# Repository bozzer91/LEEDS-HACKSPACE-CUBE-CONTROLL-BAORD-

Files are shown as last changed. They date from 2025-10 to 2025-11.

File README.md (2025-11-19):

# LEEDS HACKSPACE CUBE CONTROLL BOARD

# This READ me is a work in progress, please check back soon  :

This repository is for the new control board for the Leeds hackspace Cube art installation, this board will take input from a pc and output commands to the 16 Lines of addressable LEDS at 5v logic.  



wiring diagram visualisation ( not final revision) 



( the cube ) 

## Board info :

### Purpose : 
This control board is designed to take a Raspberry pi pico / pico-W and convert 16 data lines from 3v3 voltage to 5volt data and output this to the 16 LED strings of the Hackspace Cube. this board also includes extra ports for expansion and other functions for future upgrades. the board is about 10cm by 6cm and is deigned to be placed into an encloser with the users connectors of choice attached and soldered onto the PCB DATA outputs.   

### Reference text: 





The test points for the DATA and GPIO are as follows.
Data: to the left-hand side of the resistor above " D-1 example " the label. the left hand side is 5v

GPIO: test point to the right-hand side of the resistor below the labelling. with the left hand side being 3v3 volts

see below for the visual.



### Spare pin header :
The pin header by pins 16-28 are spare for future expansion of the cube the numbers listed on the PCB are the GPIO numbers of the pico. There are extra GND pins to the right of this pin header.



### Smothing caps :
There are 100nf smoothing caps on the main voltage rails for 5v and 3v3 these are set at locations around the board first set next to the pico and then one set pure bank of 4 logic shifters. ( see below images for examples )





### Main outputs : 
The controller board has two main Data output connectors in the form of two sets of pinheaders to connect to the users connector of choice this also mimicked the original breadboard design and allows for drop in replacement if required using the original ribbon cables. 

Connector 1 = Data 1-8 plus one GND pin
Connector 2 = Data 9-16 plus one GND pin




### Power : 
This controller board is powered by the Pico's usb input port. 

## History of this project: 

So some history of this project. back in 2022 ( give or take a covid lockdown ) it was found that the original micro controller board for the cube had broken. work was undertaken to revers engineer this board and make a replacement for 2022 Leeds lightweight. roll on to 2025 and we are still using the fear inducing Bread board that looks like something you find in a suite case in a mission impossible film that needs defusing ( see below image ) so when packing down the cube i decided to make a pcb to replace this and help move the Cube to a more user friendly plug and play design. 

BREAD BOARD 


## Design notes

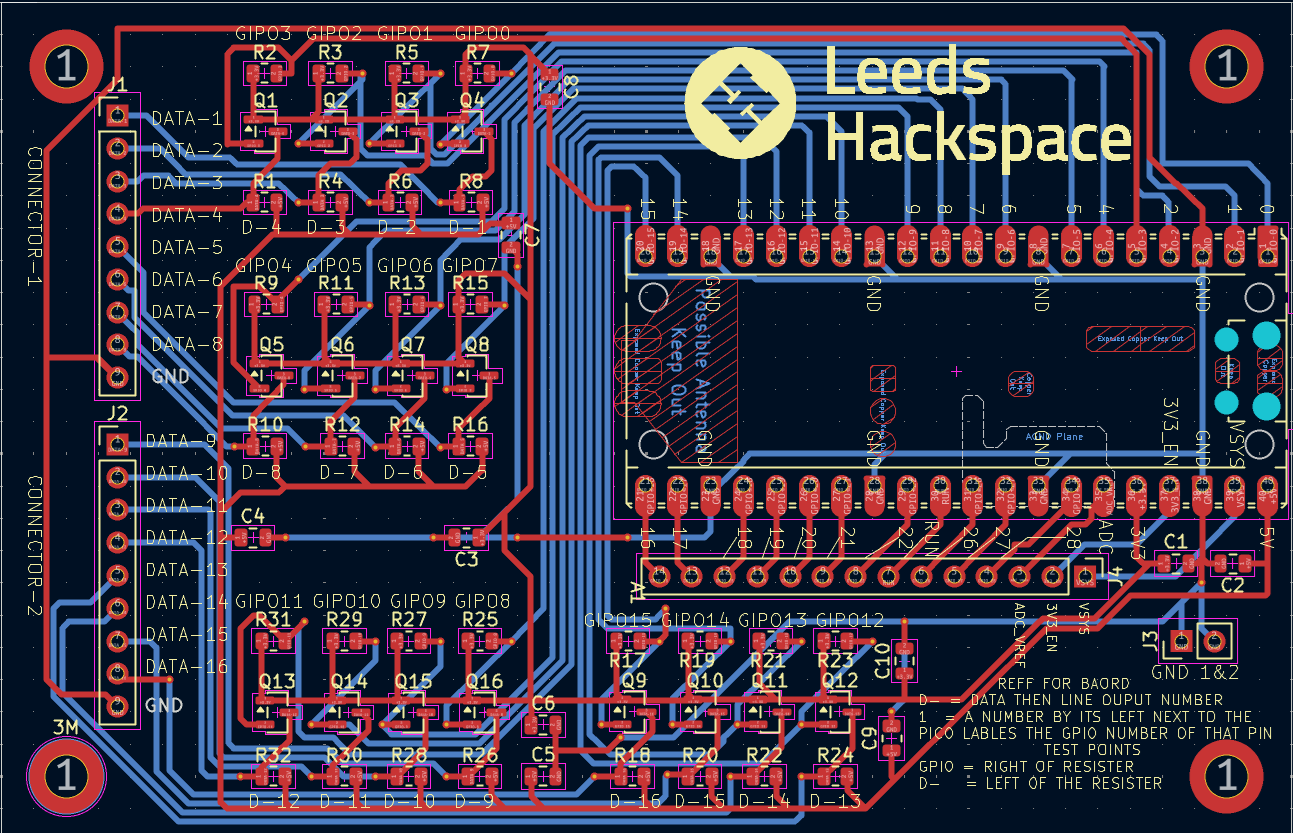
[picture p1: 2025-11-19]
Pcb layout ( spelling worng and no GND plain for easy viewing ).png

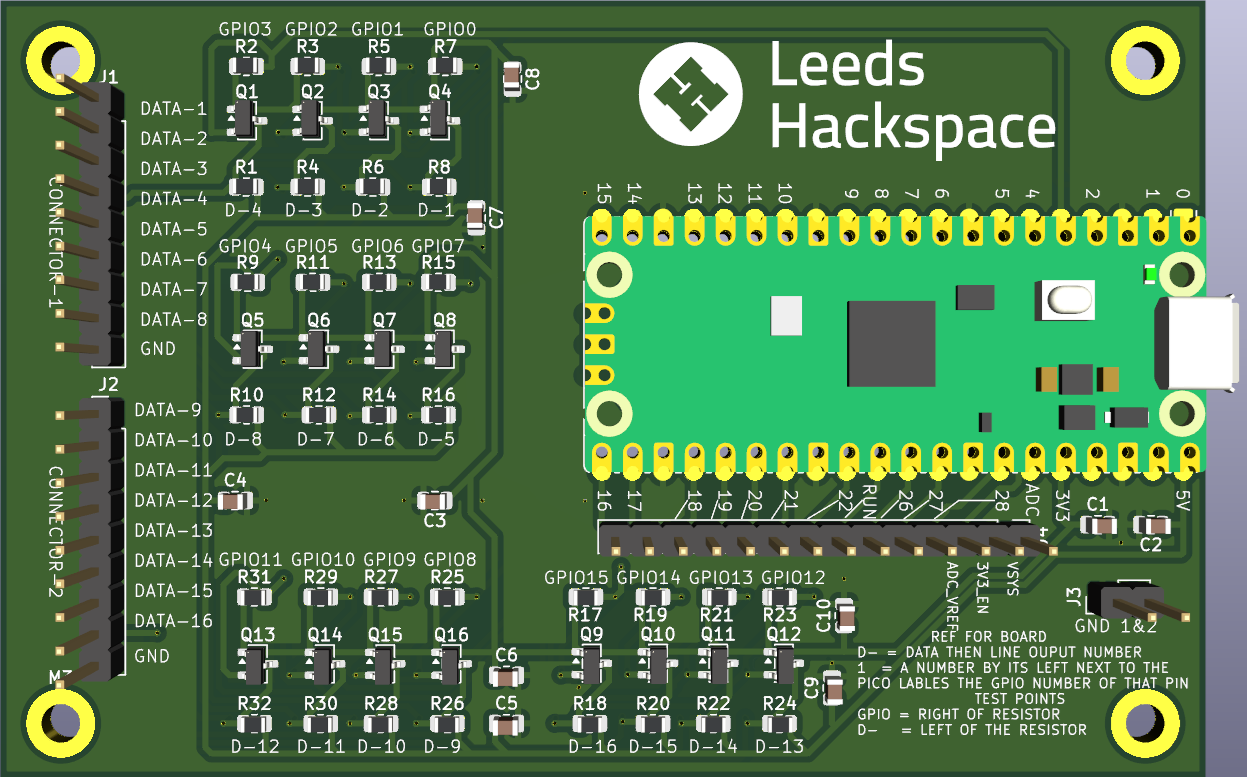
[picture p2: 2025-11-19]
PCB 3d render ( final complete version ).png

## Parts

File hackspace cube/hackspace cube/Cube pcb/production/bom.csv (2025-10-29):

Designator | Footprint | Quantity | Value | LCSC Part #
_3, _2, |  | 3
A1 | RaspberryPi_Pico_Common_Unspecified | 1 | RaspberryPi_Pico
C1, C10, C2, C3, C4, C5, C6, C7, C8, C9 | 0805 | 10 | 100nF
J1 | PinHeader_1x09_P2.54mm_Vertical | 1 | Conn_01x09 ( conector 1)
J2 | PinHeader_1x09_P2.54mm_Vertical | 1 | Conn_01x09 ( conector 2)
J3 | PinHeader_1x02_P2.54mm_Vertical | 1 | Conn_01x02 ( exstra ground conectors )
J4 | PinHeader_1x14_P2.54mm_Vertical | 1 | Conn_01x14 ( Spare Ports )
Q1, Q10, Q11, Q12, Q13, Q14, Q15, Q16, Q2, Q3, Q4, Q5, Q6, Q7, Q8, Q9 | SOT-23 | 16 | BSS138
R1, R10, R11, R12, R13, R14, R15, R16, R17, R18, R19, R2, R20, R21, R22, R23, R24, R25, R26, R27, R28, R29, R3, R30, R31, R32, R4, R5, R6, R7, R8, R9 | 0805 | 32 | 10k

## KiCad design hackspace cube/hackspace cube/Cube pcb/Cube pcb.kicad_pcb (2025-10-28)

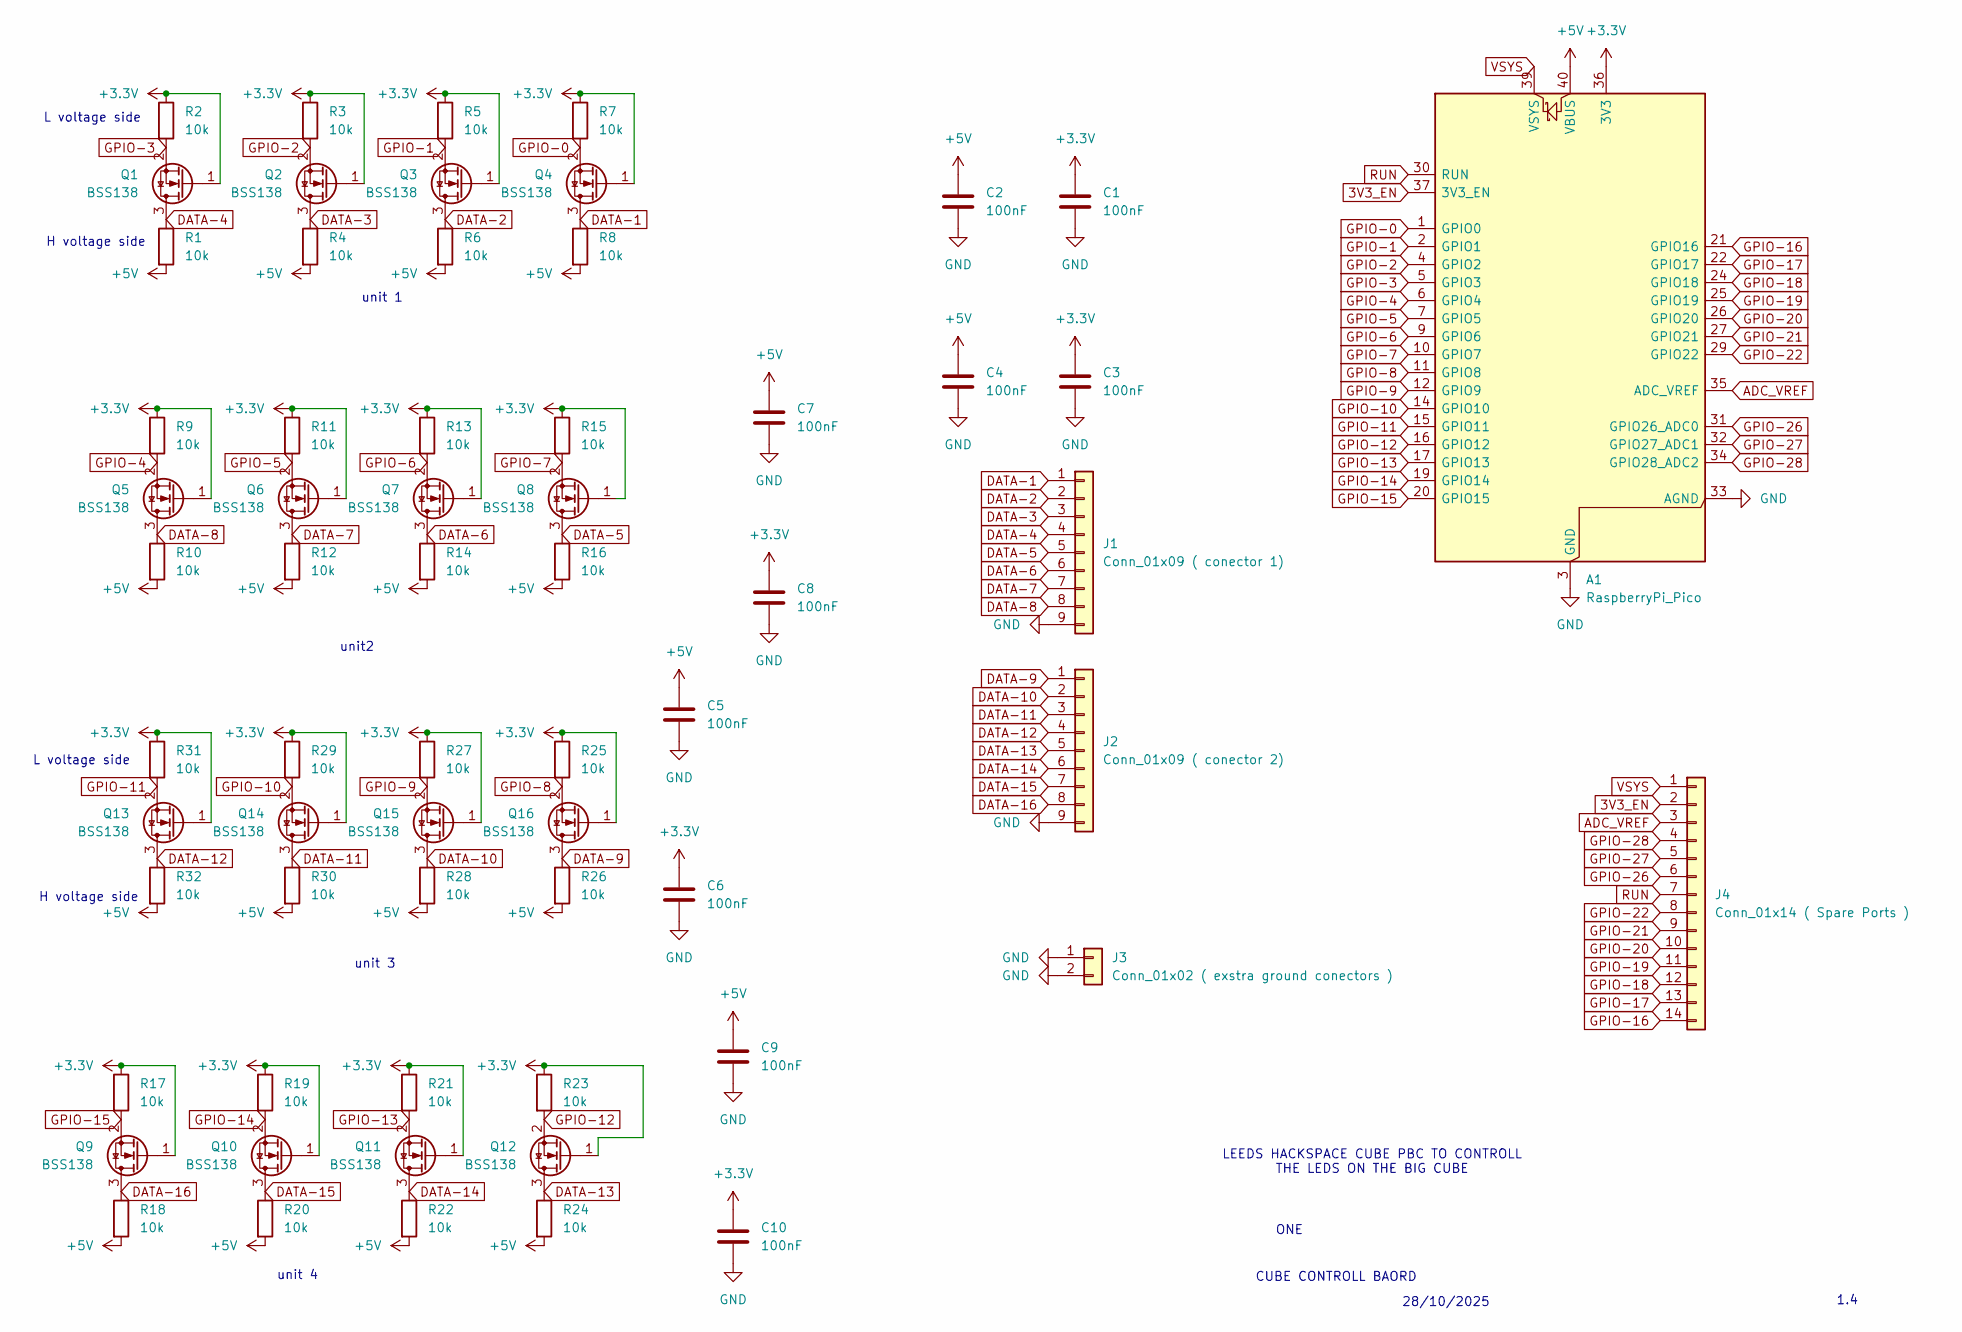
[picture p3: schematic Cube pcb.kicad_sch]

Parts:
A1: RaspberryPi_Pico; RaspberryPi_Pico_Common_Unspecified
C1, C2, C3, C4, C5, C6, C7, C8, C9, C10: 100nF; C_0805_2012Metric
J1: Conn_01x09 ( conector 1); PinHeader_1x09_P2.54mm_Vertical
J2: Conn_01x09 ( conector 2); PinHeader_1x09_P2.54mm_Vertical
J3: Conn_01x02 ( exstra ground conectors ); PinHeader_1x02_P2.54mm_Vertical
J4: Conn_01x14 ( Spare Ports ); PinHeader_1x14_P2.54mm_Vertical
Q1, Q2, Q3, Q4, Q5, Q6, Q7, Q8, Q9, Q10, Q11, Q12, Q13, Q14, Q15, Q16: BSS138; SOT-23
R1, R2, R3, R4, R5, R6, R7, R8, R9, R10, R11, R12, R13, R14, R15, R16, R17, R18, R19, R20, R21, R22, R23, R24, R25, R26, R27, R28, R29, R30, R31, R32: 10k; R_0805_2012Metric

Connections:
3V3_EN: A1.37 (3V3_EN), J4.2
+3.3V: A1.36 (3V3), C1.1, C3.1, C6.1, C8.1, C10.1, Q1.1 (G), Q2.1 (G), Q3.1 (G), Q4.1 (G), Q5.1 (G), Q6.1 (G), Q7.1 (G), Q8.1 (G), Q9.1 (G), Q10.1 (G), Q11.1 (G), Q12.1 (G), Q13.1 (G), Q14.1 (G), Q15.1 (G), Q16.1 (G), R2.1, R3.1, R5.1, R7.1, R9.1, R11.1, R13.1, R15.1, R17.1, R19.1, R21.1, R23.1, R25.1, R27.1, R29.1, R31.1
+5V: A1.40 (VBUS), C2.1, C4.1, C5.1, C7.1, C9.1, R1.2, R4.2, R6.2, R8.2, R10.2, R12.2, R14.2, R16.2, R18.2, R20.2, R22.2, R24.2, R26.2, R28.2, R30.2, R32.2
ADC_VREF: A1.35 (ADC_VREF), J4.3
DATA-1: J1.1, Q4.3 (D), R8.1
DATA-2: J1.2, Q3.3 (D), R6.1
DATA-3: J1.3, Q2.3 (D), R4.1
DATA-4: J1.4, Q1.3 (D), R1.1
DATA-5: J1.5, Q8.3 (D), R16.1
DATA-6: J1.6, Q7.3 (D), R14.1
DATA-7: J1.7, Q6.3 (D), R12.1
DATA-8: J1.8, Q5.3 (D), R10.1
DATA-9: J2.1, Q16.3 (D), R26.1
DATA-10: J2.2, Q15.3 (D), R28.1
DATA-11: J2.3, Q14.3 (D), R30.1
DATA-12: J2.4, Q13.3 (D), R32.1
DATA-13: J2.5, Q12.3 (D), R24.1
DATA-14: J2.6, Q11.3 (D), R22.1
DATA-15: J2.7, Q10.3 (D), R20.1
DATA-16: J2.8, Q9.3 (D), R18.1
GND: A1.3 (GND), A1.8 (GND), A1.13 (GND), A1.18 (GND), A1.23 (GND), A1.28 (GND), A1.33 (AGND), A1.38 (GND), C1.2, C2.2, C3.2, C4.2, C5.2, C6.2, C7.2, C8.2, C9.2, C10.2, J1.9, J2.9, J3.1, J3.2
GPIO-0: A1.1 (GPIO0), Q4.2 (S), R7.2
GPIO-1: A1.2 (GPIO1), Q3.2 (S), R5.2
GPIO-2: A1.4 (GPIO2), Q2.2 (S), R3.2
GPIO-3: A1.5 (GPIO3), Q1.2 (S), R2.2
GPIO-4: A1.6 (GPIO4), Q5.2 (S), R9.2
GPIO-5: A1.7 (GPIO5), Q6.2 (S), R11.2
GPIO-6: A1.9 (GPIO6), Q7.2 (S), R13.2
GPIO-7: A1.10 (GPIO7), Q8.2 (S), R15.2
GPIO-8: A1.11 (GPIO8), Q16.2 (S), R25.2
GPIO-9: A1.12 (GPIO9), Q15.2 (S), R27.2
GPIO-10: A1.14 (GPIO10), Q14.2 (S), R29.2
GPIO-11: A1.15 (GPIO11), Q13.2 (S), R31.2
GPIO-12: A1.16 (GPIO12), Q12.2 (S), R23.2
GPIO-13: A1.17 (GPIO13), Q11.2 (S), R21.2
GPIO-14: A1.19 (GPIO14), Q10.2 (S), R19.2
GPIO-15: A1.20 (GPIO15), Q9.2 (S), R17.2
GPIO-16: A1.21 (GPIO16), J4.14
GPIO-17: A1.22 (GPIO17), J4.13
GPIO-18: A1.24 (GPIO18), J4.12
GPIO-19: A1.25 (GPIO19), J4.11
GPIO-20: A1.26 (GPIO20), J4.10
GPIO-21: A1.27 (GPIO21), J4.9
GPIO-22: A1.29 (GPIO22), J4.8
GPIO-26: A1.31 (GPIO26_ADC0), J4.6
GPIO-27: A1.32 (GPIO27_ADC1), J4.5
GPIO-28: A1.34 (GPIO28_ADC2), J4.4
RUN: A1.30 (RUN), J4.7
VSYS: A1.39 (VSYS), J4.1

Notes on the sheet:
CUBE CONTROLL BAORD
unit 4
LEEDS HACKSPACE CUBE PBC TO CONTROLL THE LEDS ON THE BIG CUBE
unit 1
unit2
28/10/2025
unit 3
1.4
H voltage side
ONE
L voltage side

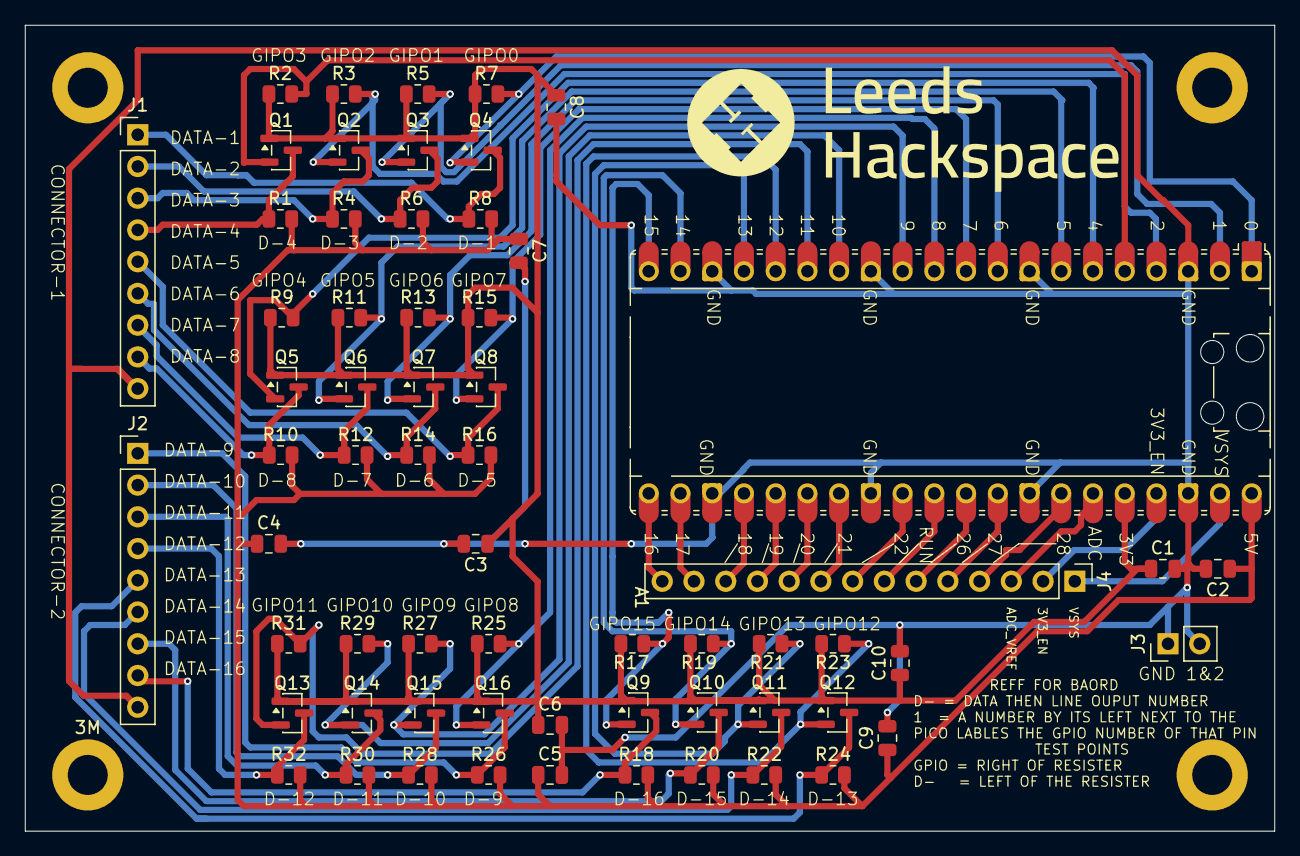
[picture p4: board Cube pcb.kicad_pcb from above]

Board: 2 copper layers, 100.0 x 64.5 mm, 64 parts (0 on the bottom side), 49 nets.

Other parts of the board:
3M: MountingHole_3.2mm_M3_ISO7380_Pad

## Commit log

2025-10-25 CUBE KI CAD FILES
2025-10-25 rev1.2 with pcb
    starting on pcb design
    [Cube pcb.kicad_pcb, Cube pcb.kicad_sch]
2025-10-26 updating pcb
    updating pcb most pins attached
    [Cube pcb.kicad_pcb]
2025-10-26 pcb first draft
    [Cube pcb.kicad_pcb, Cube pcb.kicad_sch]
2025-10-26 Update README.md
    UPDATING WITH INFO ON THE PCB
2025-10-26 update pcb
    i have added labels and basic info onto the pcb
    [Cube pcb.kicad_pcb]
2025-10-27 updated wiring D and PCB
    wiring D now has GND on the connector pins . PCB now has new shorter design to make it 10cm wide just need to add ground plain
    [Cube pcb.kicad_pcb, Cube pcb.kicad_sch]
2025-10-27 new pcb file
    new pcb file to add ground plain before sending off
    [Cube pcb - with ground plain.kicad_pcb]
2025-10-27 ground plain added
    ground plain added
    [Cube pcb - with ground plain.kicad_pcb]
2025-10-28 rev 1.4
    added new smooth caps and updated pcb
    [Cube pcb - with ground plain2.kicad_pcb, Cube pcb.kicad_pcb, Cube pcb.kicad_sch]
2025-10-28 DRC check done
    [Cube pcb - with ground plain2.kicad_pcb]
2025-10-29 pcb fab files
    new test pcb fab files created
    [Cube pcb - with ground plain2.kicad_pcb, Cube pcb BOM.csv, bom.csv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]
2025-10-31 updated spelling
    updated spelling using NavSpellCheck
    [Cube pcb - with ground plain2.kicad_pcb, bom.csv, designators.csv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]
2025-10-31 fixed more spelling
    [Cube pcb - with ground plain2.kicad_pcb, Cube pcb BOM.csv, designators.csv]

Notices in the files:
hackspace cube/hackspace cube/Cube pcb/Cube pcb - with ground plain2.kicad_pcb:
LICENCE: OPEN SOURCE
